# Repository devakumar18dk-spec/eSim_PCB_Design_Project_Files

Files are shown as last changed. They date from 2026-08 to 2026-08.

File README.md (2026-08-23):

<div align="center">

# ⚡ Enhanced Power Supply ESP32

### Wide-Input (7–24 V) ESP32-C3 Development Board — A Complete Embedded Hardware Platform

**Designed & Simulated in FOSSEE eSim (KiCad-based workflow)**


















</div>

<br>

<p align="center">
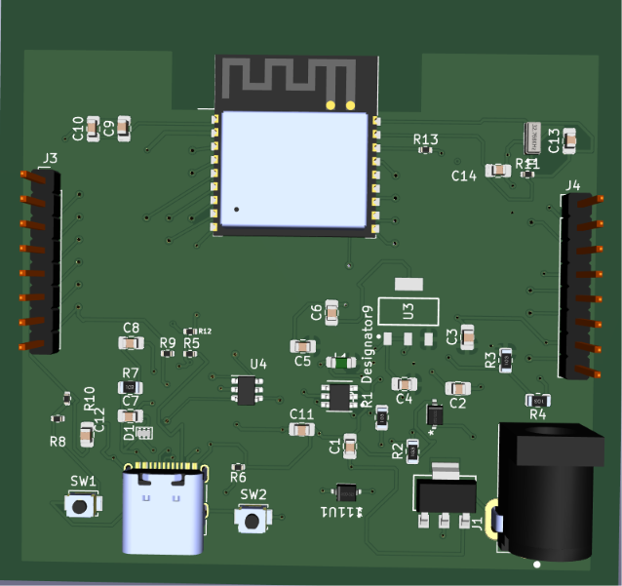
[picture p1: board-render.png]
Enhanced Power Supply ESP32 — 3D Render
  
</p>

<p align="center"><sub>🧊 3D render of the routed 4-layer board — ESP32-C3-WROOM-02, USB-C, DC barrel jack, and dual GPIO headers.</sub></p>

<div align="center">

`Power In (7–24V)` → `Protection` → `5V Buck` → `3.3V LDO` → `ESP32-C3` ⚡

</div>

```bash
git clone https://github.com/devakumar18dk-spec/eSim_PCB_Design_Project_Files.git
```

---

## 📖 Table of Contents

- [Overview](#-overview)
- [Highlights & Features](#-highlights--features)
- [System Architecture](#-system-architecture)
- [Power Architecture](#-power-architecture)
- [USB-C Interface](#-usb-c-interface)
- [Boot & Reset Control](#-boot--reset-control)
- [RTC Timing](#-rtc-timing)
- [GPIO Expansion](#-gpio-expansion)
- [PCB Design (4-Layer)](#-pcb-design-4-layer)
- [📐 Schematic](#-schematic)
- [🖼 PCB Layout](#-pcb-layout)
- [Technical Specifications](#-technical-specifications)
- [Design Verification Checklist](#-design-verification-checklist)
- [Hardware Bring-Up Sequence](#-hardware-bring-up-sequence)
- [Design Workflow](#-design-workflow)
- [Repository Structure](#-repository-structure)
- [Getting Started](#-getting-started)
- [Contributing](#-contributing)
- [License](#-license)
- [Acknowledgements](#-acknowledgements)

---

## 🧭 Overview

This project presents the design and PCB implementation of a custom **ESP32-C3-based development board**, engineered end-to-end using the **FOSSEE eSim electronics design environment**. Rather than functioning as a simple ESP32 breakout, this board is architected as a **complete embedded hardware platform** — integrating wide-range DC power input, robust input protection, two-stage voltage regulation, USB-C connectivity with ESD protection, hardware boot/reset control, RTC timing, and expandable GPIO — all realized on a **four-layer PCB**.

> **Design philosophy:** protect first, convert efficiently, regulate cleanly, then compute. Every subsystem exists to deliver a stable, low-noise supply and a reliable interface to the ESP32-C3.

```
7–24 V DC  →  Protection  →  5 V Buck  →  3.3 V LDO  →  ESP32-C3
```

---

## ✨ Highlights & Features

<table>
<tr>
<td width="50%" valign="top">

### 🔋 Power System
- Wide **7 V – 24 V DC** input range
- Reverse-polarity protection via **P-channel MOSFET**
- **TVS/Zener** transient (surge) protection
- Two-stage regulation: **Buck (5 V) → LDO (3.3 V)**
- Local bulk + high-frequency decoupling at the MCU

### 🔌 Connectivity
- **USB Type-C** interface (16-pin receptacle)
- CC1/CC2 configuration resistors (device/sink mode)
- Dedicated **USBLC6-2SC6** ESD protection on D+/D−
- USB used strictly for data/programming — **not** primary power

</td>
<td width="50%" valign="top">

### 🧠 Control & Expansion
- **ESP32-C3-WROOM-02** central controller
- Dedicated **EN (Reset)** and **IO9 (Boot)** push buttons
- **32.768 kHz RTC crystal** for low-power timekeeping
- **2 × 8-pin, 2.54 mm** GPIO expansion headers

### 🧱 PCB Engineering
- **4-layer stack-up**: Power / Signal / Mixed / Ground
- Dedicated **ESP32 antenna keep-out zone**
- Functionally-grouped component placement
- Continuous ground plane for low-impedance return paths

</td>
</tr>
</table>

---

## 🏗 System Architecture

The board is organized into five functional sections: **Power**, **USB-C**, **Main Controller**, **Boot/Reset**, and **GPIO/Expansion**.

```
                  ESP32-C3 DEVELOPMENT BOARD
                           │
       ┌───────────────────┼───────────────────┐
       │                   │                   │
       ▼                   ▼                   ▼
 POWER SYSTEM         USB-C SYSTEM       CONTROL / I/O
       │                   │                   │
  7–24 V DC           USB Type-C          Boot Button
       │                   │               Reset Button
       ▼                   │                   │
 Input Protection          │                   │
       │                   │                   │
       ▼                   ▼                   ▼
 5 V Buck              ESD Protection      ESP32-C3
       │                   │                   │
       ▼                   ▼              GPIO Headers
 5 V Rail              USB D+/D−
       │
       ▼
 3.3 V LDO
       │
       ▼
  +3.3 V Rail
       │
       ▼
  ESP32-C3 WROOM-02
       │
       └── 32.768 kHz RTC Crystal
```

---

## 🔋 Power Architecture

Every subsystem on this board depends on a stable, protected supply — so power is treated as the primary design driver, not an afterthought.

### Main Power Path

```
DC Input → Protection → Buck Converter (5 V) → LDO (3.3 V) → ESP32-C3
```

The board deliberately avoids converting the full 7–24 V range directly to 3.3 V with a linear regulator. Instead, a **switching regulator** absorbs the large voltage difference efficiently, while an **LDO** performs final, low-noise regulation — the right tool for each job.

<details>
<summary><b>🛡️ Input Protection — click to expand</b></summary>

<br>

| Function | Component | Behavior |
|---|---|---|
| Transient protection | TVS / Zener network | Inactive under normal operation; clamps excess voltage during spikes |
| Reverse-polarity protection | P-channel MOSFET (STN3P6F6) | Low-resistance conduction on correct polarity; blocks reverse voltage |

```
Correct polarity          Incorrect polarity
      │                          │
      ▼                          ▼
P-MOSFET conducts          MOSFET blocks
      │                          │
      ▼                          ▼
Power reaches regulator    Downstream circuitry protected
```

A P-MOSFET is used instead of a conventional diode because it offers **much lower conduction loss**.

</details>

<details>
<summary><b>⚙️ 5 V Buck Conversion — click to expand</b></summary>

<br>

The protected input feeds the **LMR50410-Q1** switching regulator, which converts **7–24 V → 5 V** by transferring energy through controlled switching rather than dissipating the difference as heat.

**Supporting components:** 4.7 µH inductor · bootstrap capacitor · input/output capacitors · feedback resistor network · 10 µF local input capacitor (placed close to the regulator to keep the high-frequency current loop compact).

```
7–24 V ─► Switching Node ─► 4.7 µH Inductor ─► Output Filter ─► 5 V
```

</details>

<details>
<summary><b>🎯 3.3 V LDO Post-Regulation — click to expand</b></summary>

<br>

The 5 V rail feeds an **LM1117-3.3** LDO, which handles only the small **5 V → 3.3 V** step. This division of labor means:

| Stage | Responsibility |
|---|---|
| Buck | Efficient large voltage conversion (7–24 V → 5 V) |
| LDO | Final clean regulation, ripple attenuation, low-impedance supply |

The LDO also provides power-supply rejection within its effective PSRR band, attenuating residual switching ripple before it reaches the ESP32-C3.

</details>

<details>
<summary><b>📎 MCU Decoupling — click to expand</b></summary>

<br>

Local **4.7 µF** (bulk) and **100 nF** (high-frequency) capacitors sit right at the ESP32-C3 supply pins, supplying transient current locally instead of forcing it through long PCB traces from the regulator — reducing supply impedance seen by the controller.

</details>

<div align="right"><sub><a href="#-enhanced-power-supply-esp32">⬆ back to top</a></sub></div>

---

## 🔌 USB-C Interface

The USB-C section is an **independent communication interface**, cleanly separated from the main power path.

| Element | Detail |
|---|---|
| Connector | USB Type-C, 16-pin |
| CC configuration | 2 × 5.1 kΩ on CC1/CC2 → configures board as USB-C sink/device |
| ESD protection | USBLC6-2SC6, placed near the connector |
| Role | Data / programming only — **not** the primary power source |

```
External USB Connector → ESD Protection → ESP32-C3
```

Keeping USB power and main DC power separate lets the board run continuously from the 7–24 V input while still using USB freely for programming and debugging.

---

## 🛠 Boot & Reset Control

| Button | Signal | Function |
|---|---|---|
| Reset | EN | 10 kΩ pull-up; pressing forces EN low and resets the MCU |
| Boot | IO9 | 10 kΩ pull-up; pressing changes boot-strap state to enter programming mode |

```
USB connected → Hold BOOT → Reset ESP32-C3 → Enters programming mode
```

---

## ⏱ RTC Timing

A **32.768 kHz crystal** provides an external low-frequency timing reference for the ESP32-C3 RTC. It's placed close to the module to minimize parasitics and kept away from the buck converter's switching node to avoid noise coupling.

---

## 🧩 GPIO Expansion

Two **8-pin, 2.54 mm pitch headers** expose selected ESP32-C3 GPIOs, turning the board into a reusable development platform for sensors, LEDs, displays, communication modules, and breadboard prototyping.

---

## 🧱 PCB Design (4-Layer)

| Layer | Purpose |
|---|---|
| **F.Cu** (Top) | Power distribution & primary component routing |
| **In1.Cu** | Signal routing (GPIO fan-out from the ESP32-C3) |
| **In2.Cu** | Mixed-purpose routing / secondary distribution |
| **B.Cu** (Bottom) | Continuous ground plane |

<details>
<summary><b>📍 Component Placement Strategy</b></summary>

<br>

| Region | Contents | Rationale |
|---|---|---|
| Upper | ESP32-C3 module, antenna toward board edge | Unobstructed RF environment |
| Central | Buck converter, LDO, protection circuitry, USB-C | Short, low-impedance power connections |
| Lower | Boot/Reset buttons | User accessibility |
| Sides | GPIO headers (left & right) | Convenient external interfacing |

</details>

<details>
<summary><b>📡 Antenna Keep-Out</b></summary>

<br>

A clearly defined **keep-out zone** sits above the ESP32-C3 module — no copper, tracks, or vias are routed through this area, per module manufacturer guidance, to prevent detuning or shielding the integrated antenna.

</details>

<details>
<summary><b>🧵 Routing & Grounding Philosophy</b></summary>

<br>

- **High-current power paths** — short and comparatively wide (DC input, MOSFET, buck, inductor, 5 V rail, LDO)
- **Switching node** — kept as small as practical to limit EMI coupling
- **USB D+/D−** — routed as a matched differential pair, ESD device close to the connector
- **RTC crystal traces** — short, isolated from switching noise
- **Ground plane (B.Cu)** — continuous reference plane minimizing loop area, EMI, and supply noise — especially important given the ESP32-C3's onboard radio

</details>

<details>
<summary><b>🌡️ Thermal Considerations</b></summary>

<br>

Primary heat sources are the **buck converter**, **LDO**, and **protection MOSFET**. The LDO has the most predictable thermal profile since it dissipates the 5 V→3.3 V difference directly — adequate copper area is provided around its thermal pads per datasheet recommendations.

</details>

---

## 📐 Schematic

<p align="center">
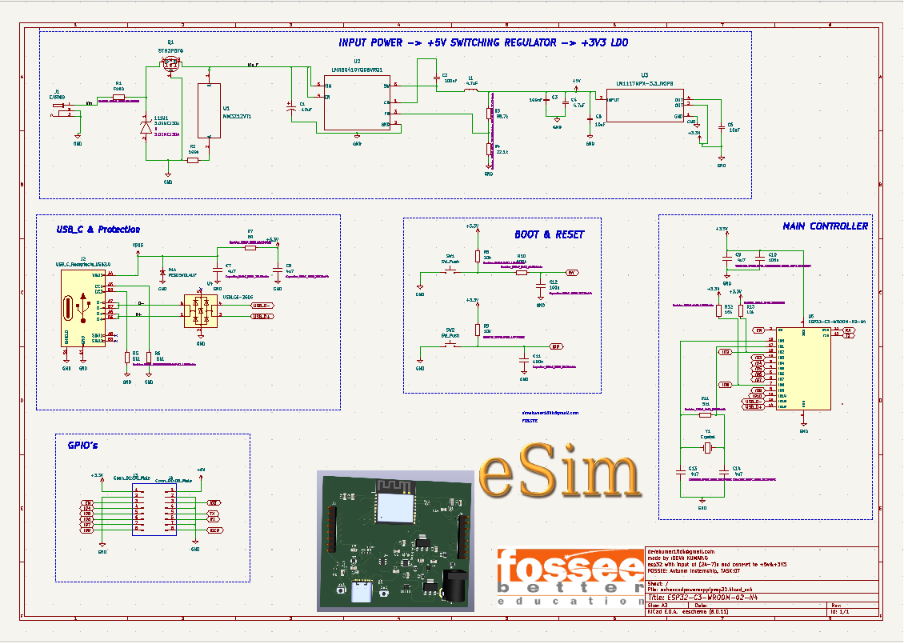
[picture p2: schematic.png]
Full Circuit Schematic
  
</p>

<div align="center">

| 🔋 Input → 5V → 3.3V | 🔌 USB-C & ESD | 🛠 Boot & Reset | 🧠 Main Controller | 🧩 GPIOs |
|:---:|:---:|:---:|:---:|:---:|
| ST6P3F6, LMR50410-Q1, LM1117-3.3 | USB-C receptacle, USBLC6-2SC6 | EN & IO9 push buttons | ESP32-C3-WROOM-02 | 2 × 8-pin headers |

</div>

<p align="center"><sub>📄 Captured entirely in <b>FOSSEE eSim</b> — five functional blocks laid out for clarity: power regulation (top), USB-C/protection, boot/reset, and GPIO breakout (bottom row), with the main ESP32-C3 controller on the right.</sub></p>

---

## 🖼 PCB Layout

The board is routed across **four copper layers**, each with a distinct role. Toggle through the stack below — every view shares the same silhouette so you can trace a single net (e.g. GND) from top to bottom.

<table align="center">
<tr>
<th align="center">🟥 F.Cu — Power / Top Layer</th>
<th align="center">🟩 In1.Cu — Signal Layer</th>
</tr>
<tr>
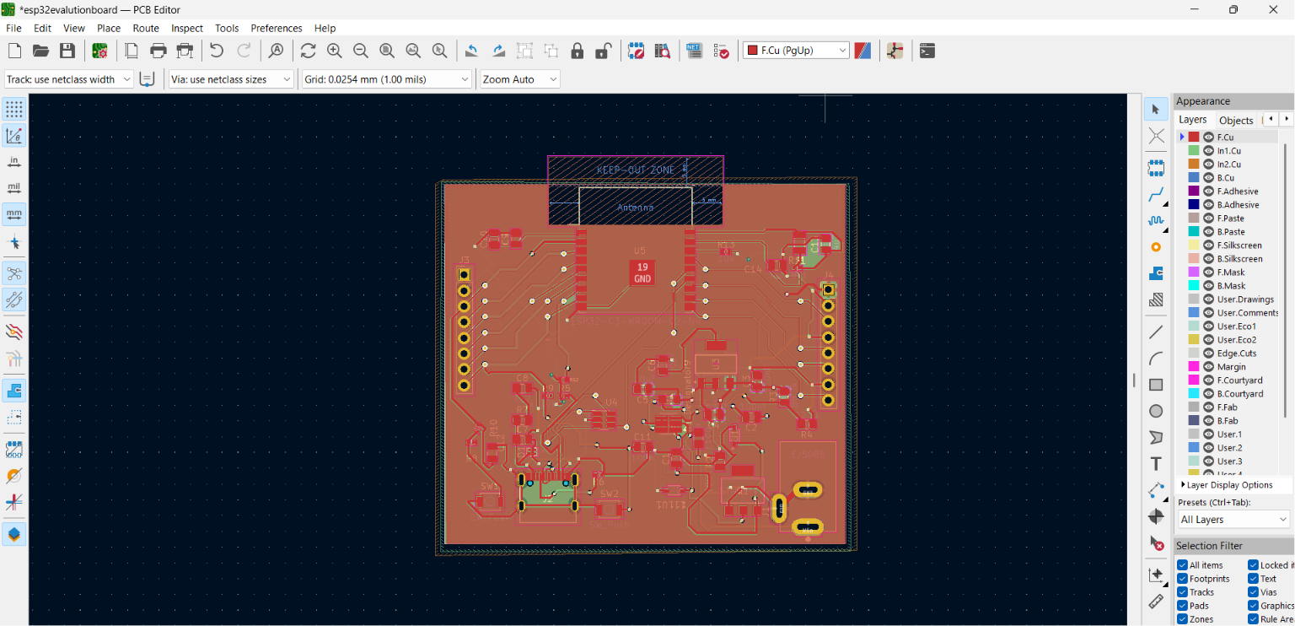
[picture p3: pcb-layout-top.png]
<td></td>
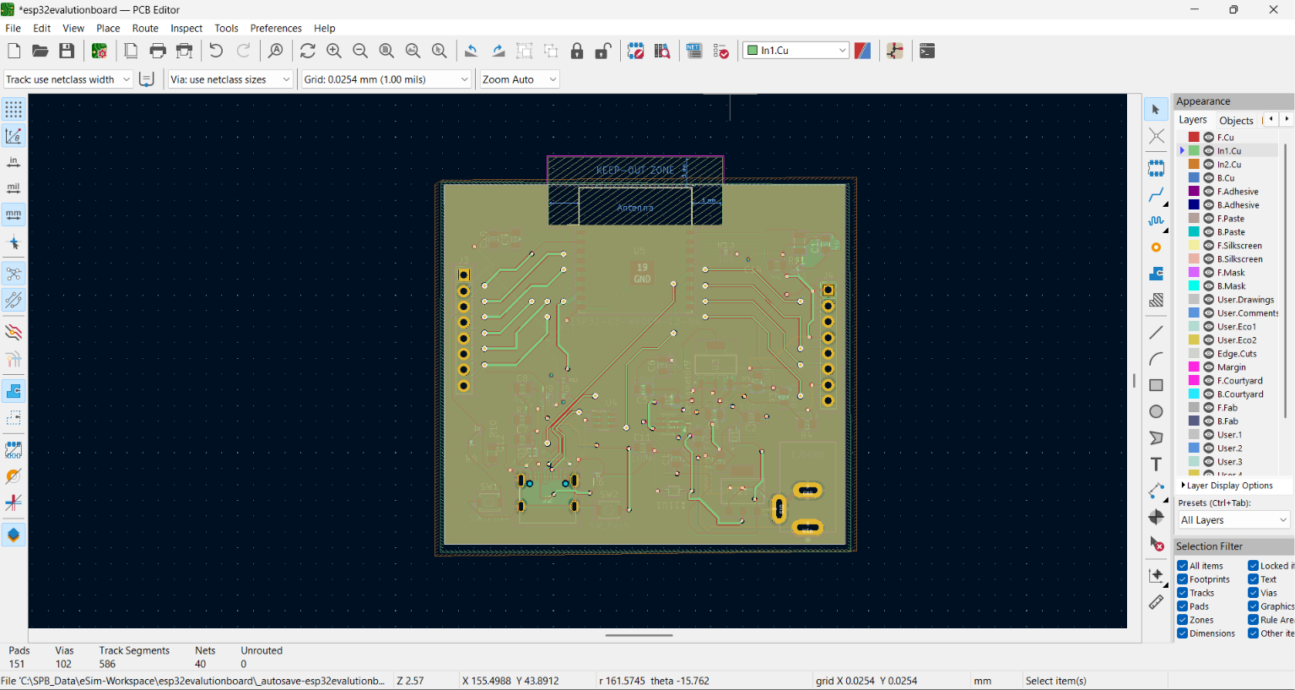
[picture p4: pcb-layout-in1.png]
<td></td>
</tr>
<tr>
<td align="center"><sub>Primary power distribution & component-side routing</sub></td>
<td align="center"><sub>ESP32-C3 GPIO fan-out toward J3 / J4 headers</sub></td>
</tr>
<tr>
<th align="center">🟧 In2.Cu — Mixed Routing Layer</th>
<th align="center">🟦 B.Cu — Ground Plane</th>
</tr>
<tr>
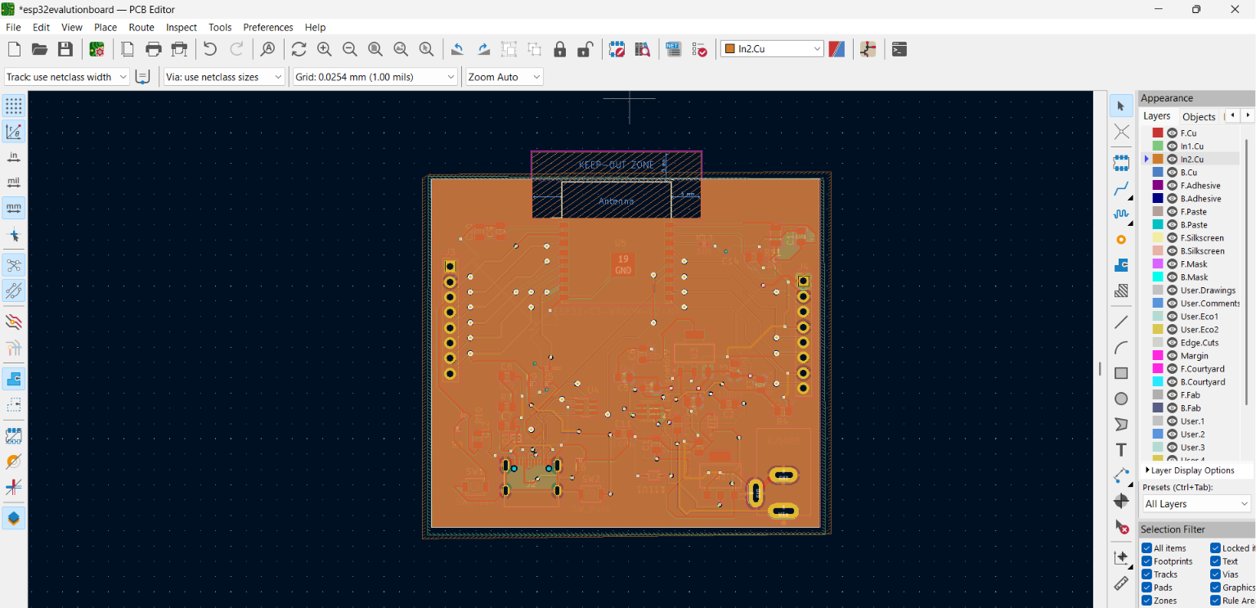
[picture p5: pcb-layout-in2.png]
<td></td>
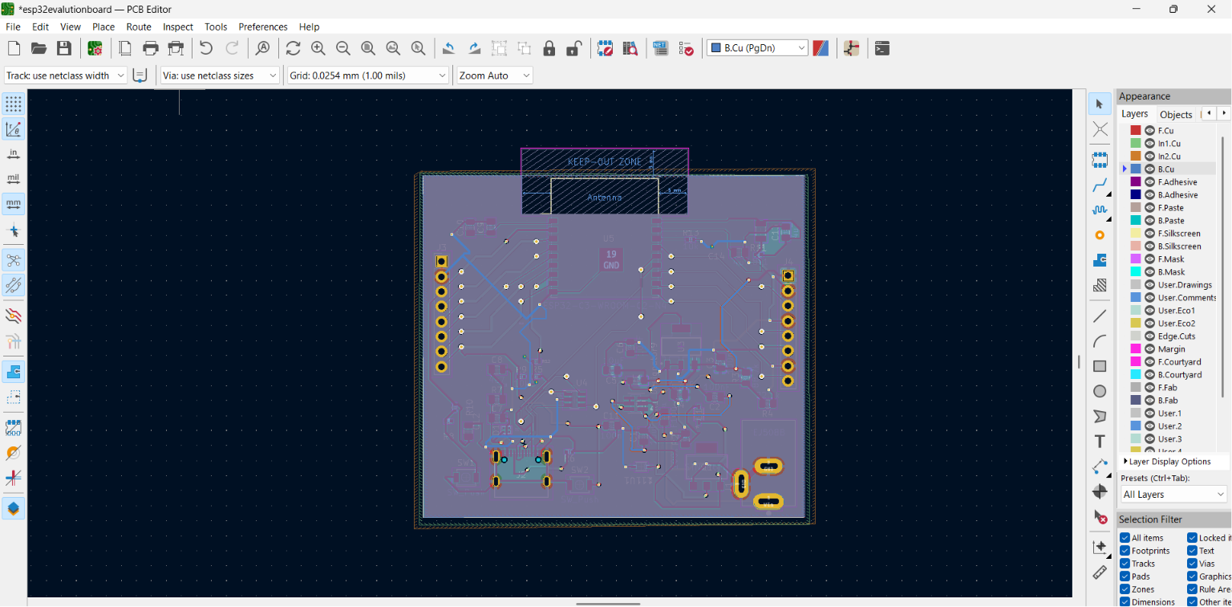
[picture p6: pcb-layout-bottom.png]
<td></td>
</tr>
<tr>
<td align="center"><sub>Secondary power/signal distribution channel</sub></td>
<td align="center"><sub>Continuous ground reference plane</sub></td>
</tr>
</table>

> 🛰️ **Antenna Keep-Out Zone** — visible as the hatched `KEEP-OUT ZONE / Antenna` region above the ESP32-C3 module on every layer. No copper, tracks, or vias are routed through this area to protect RF performance.

<details>
<summary><b>📊 Routing Stats (from PCB editor)</b></summary>

<br>

| Metric | Count |
|---|---|
| Pads | 151 |
| Vias | 102 |
| Nets | 586 |
| Unrouted | 0 ✅ |

</details>

<div align="right"><sub><a href="#-enhanced-power-supply-esp32">⬆ back to top</a></sub></div>

---

## 📋 Technical Specifications

| Specification | Design |
|---|---|
| MCU | ESP32-C3-WROOM-02 |
| Main DC input | 7–24 V |
| Primary power connector | DC input connector |
| Input protection | TVS/Zener + P-channel MOSFET |
| Reverse polarity protection | STN3P6F6 P-MOSFET |
| Buck regulator | LMR50410-Q1 |
| Buck output | 5 V |
| Buck inductor | 4.7 µH |
| Post-regulator | LM1117-3.3 |
| Final logic rail | 3.3 V |
| RTC reference | 32.768 kHz crystal |
| USB connector | USB Type-C, 16-pin |
| USB CC resistors | 5.1 kΩ × 2 |
| USB ESD protection | USBLC6-2SC6 |
| Reset control | EN push button |
| Boot control | IO9 push button |
| Button pull-ups | 10 kΩ |
| GPIO expansion | 2 × 8-pin headers |
| GPIO header pitch | 2.54 mm |
| PCB structure | 4-layer |
| F.Cu | Primary power / component routing |
| In1.Cu | Signal routing |
| In2.Cu | Mixed routing / distribution |
| B.Cu | Ground plane |
| RF provision | ESP32 antenna keep-out |
| Design environment | FOSSEE eSim / KiCad-based workflow |

---

## ✅ Design Verification Checklist

<table>
<tr>
<td width="50%" valign="top">

**Schematic Checks**
- [ ] All power nets verified
- [ ] 3.3 V connections verified
- [ ] 5 V connections verified
- [ ] All ground connections verified
- [ ] ESP32-C3 power pins checked
- [ ] Boot strapping verified
- [ ] EN/reset circuitry verified
- [ ] USB D+/D− connections verified
- [ ] USB CC resistors verified
- [ ] No unintended VBUS-to-3.3 V paths

</td>
<td width="50%" valign="top">

**PCB Checks**
- [ ] Design Rule Check (DRC) passed
- [ ] Track widths verified
- [ ] Clearances verified
- [ ] Via placement checked
- [ ] Copper-zone connections checked
- [ ] Antenna keep-out respected
- [ ] Silkscreen overlaps checked
- [ ] Connector orientation verified
- [ ] Footprint pin numbering verified
- [ ] Mounting/mechanical dimensions verified

</td>
</tr>
</table>

<div align="right"><sub><a href="#-enhanced-power-supply-esp32">⬆ back to top</a></sub></div>

---

## 🧪 Hardware Bring-Up Sequence

> Do **not** connect the ESP32 module immediately after fabrication — follow a controlled sequence.

| Step | Test | Expected Result |
|---|---|---|
| 1 | Input protection | Protected input rail stable across 7–24 V |
| 2 | Buck converter | ~**+5 V** at buck output (before connecting downstream circuitry) |
| 3 | LDO | ~**+3.3 V** at LDO output |
| 4 | MCU power | ESP32-C3 receives correct 3.3 V supply |
| 5 | Reset | Pressing EN resets the MCU |
| 6 | Boot | IO9 + reset sequencing enters programming mode |
| 7 | USB | USB enumeration / programming succeeds |
| 8 | GPIO | Expansion headers verified with simple GPIO firmware |
| 9 | RTC | 32.768 kHz RTC functionality confirmed |

---

## 🔁 Design Workflow

```
System Requirements → Circuit Architecture → Component Selection
        → Schematic Capture (eSim) → Electrical Connectivity Verification
        → Footprint Assignment → PCB Layout → 4-Layer Stack-up
        → Component Placement → Power Routing → Signal Routing
        → Ground Plane → Antenna Keep-Out → Design Rule Check
        → Gerber / Manufacturing Files → PCB Fabrication → Hardware Testing
```

---

## 🗂 Repository Structure

```
eSim_PCB_Design_Project_Files/
├── assets/
│   └── images/
│       ├── board-render.png       # 3D render
│       ├── schematic.png          # Full eSim schematic
│       ├── pcb-layout-top.png     # F.Cu — power layer
│       ├── pcb-layout-in1.png     # In1.Cu — signal layer
│       ├── pcb-layout-in2.png     # In2.Cu — mixed layer
│       └── pcb-layout-bottom.png  # B.Cu — ground plane
├── hardware/
│   ├── schematic/          # eSim / KiCad schematic project files
│   ├── pcb/                # PCB layout project files
│   └── gerbers/            # Manufacturing output (Gerbers, drill files, BOM)
├── docs/
│   └── technical-report.md # Full design & verification report
├── firmware/                # (optional) example/bring-up firmware
├── LICENSE
└── README.md
```

---

## 🚀 Getting Started

1. **Clone the repository**
   ```bash
   git clone https://github.com/devakumar18dk-spec/eSim_PCB_Design_Project_Files.git
   cd eSim_PCB_Design_Project_Files
   ```
2. **Open the schematic/PCB** in FOSSEE eSim or KiCad from the `hardware/` directory.
3. **Review the Gerbers** in `hardware/gerbers/` before sending to fabrication.
4. **Follow the [Hardware Bring-Up Sequence](#-hardware-bring-up-sequence)** after assembly.
5. **Flash firmware** over USB-C once power rails are verified.

---

## 🤝 Contributing

Contributions, issues, and design suggestions are welcome! Feel free to open a pull request or start a discussion if you'd like to improve the power architecture, layout, or documentation.

---

## 📄 License

This project is released under the **MIT License** — see [`LICENSE`](LICENSE) for details. *(Update if a different license applies.)*

---

## 🙌 Acknowledgements

- **FOSSEE eSim** — schematic capture and simulation environment
- **KiCad** — PCB layout workflow
- **Espressif Systems** — ESP32-C3-WROOM-02 module

---

<div align="center">

### 🧩 Built as a complete embedded hardware platform — not just an ESP32 carrier board.

**Wide-range power management · Protection · Wireless processing · USB-C · Hardware boot control · RTC · Expandable I/O**
**— all in a single four-layer PCB.**




**⭐ If this project helped you, consider starring the repository!**

[⬆ Back to top](#-enhanced-power-supply-esp32)

</div>

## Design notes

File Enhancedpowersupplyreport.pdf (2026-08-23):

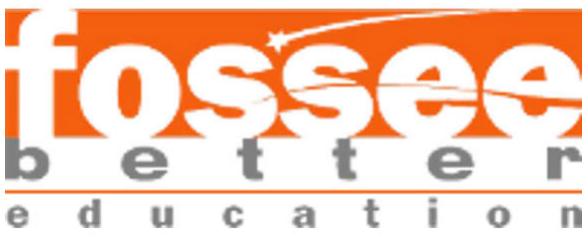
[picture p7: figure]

# eSim

SEMESTER LONG INTERNSHIP – AUTUMN 2026 INTERNSHIP SCREENING TASK REPORT Task 7 – PCB Design using eSim

# Enhanced Power Supply ESP32

Wide-Input (7–24 V) ESP32-C3 Development Board

Prepared by Deva Kumar G, II Year Department of VLSI Design and Technology Chennai Institute of Technology

PCB – ESP32C3-EPS

Enhanced Power Supply ESP32 — FOSSEE Autumn Internship 2026 | Page 2

# 1. Project Overview

This report presents the complete printed circuit board (PCB) design and schematic files for a custom, wide-input ESP32-C3 microcontroller development board. The design was developed as part of the screening task for the FOSSEE Autumn Internship 2026 program conducted by IIT Bombay.

The primary objective of this project was to design a fully functional, manufacturable development board centred around the ESP32-C3-WROOM-02 module — one that goes beyond a simple breakout board. Rather than exposing the module directly to an external supply, the board implements a complete power architecture that accepts a wide 7–24 V DC input, protects against reverse polarity and transient events, and steps the supply down through a two-stage regulator chain before it ever reaches the microcontroller.

The design was realised as a custom 4-layer PCB stack-up, optimised for power distribution, signal integrity, and RF-aware component placement around the module's integrated antenna.

## Key Project Details

Microcontroller | ESP32-C3-WROOM-02 (RISC-V single-core, 160 MHz, Wi-Fi + BLE 5, integrated antenna)
Design Tools | FOSSEE eSim 2.5 (schematic capture) KiCad (PCB layout, integrated via eSim)
Power Input | Wide-range 7–24 V DC via dedicated DC input connector
Regulation Architecture | Protected input → LMR50410-Q1 buck (5 V) → LM1117-3.3 LDO (3.3 V)
USB Interface | USB Type-C, 16-pin — data/programming only, not the primary power source
PCB Stack-up | 4-layer: F.Cu (power) / In1.Cu (signal) / In2.Cu (mixed) / B.Cu (ground)
Verification Status | Schematic connectivity and PCB design-rule checks completed with zero unresolved errors

The finished design includes a fully routed 4-layer stack-up and a 3D visual model for verifying component placement and mechanical fit ahead of fabrication.

# 2. Circuit Description

## 2.1 Power Supply Section

The board operates from a two-stage regulated supply rather than a single linear conversion from the wide input range. The external 7–24 V DC source first passes through an input protection stage comprising a TVS/Zener transient-clamping network and a P-channel MOSFET (STN3P6F6) configured for reverse-polarity protection. Under correct polarity the MOSFET conducts with very low resistance; if the supply is connected in reverse, it blocks the path entirely and protects every downstream component.

The protected input then feeds the LMR50410-Q1 synchronous buck converter, which efficiently steps the 7–24 V input down to an intermediate 5 V rail using a 4.7 uH inductor and a 10 uF local input capacitor placed close to the regulator to keep the high-frequency switching loop compact. The 5 V rail is not used directly by the MCU — it feeds an LM1117-3.3 LDO, which performs the final, low-noise regulation down to 3.3 V. Splitting the conversion this way lets the buck stage absorb the large voltage difference efficiently,

Enhanced Power Supply ESP32 — FOSSEE Autumn Internship 2026 | Page 3

while the LDO concentrates purely on ripple rejection and supply cleanliness for the sensitive digital domain.

Local 4.7 uF bulk and 100 nF high-frequency decoupling capacitors are placed directly at the ESP32-C3 power pins to supply transient current locally and minimise supply impedance during rapid load changes (e.g. Wi-Fi transmit bursts).

## 2.2 Clock and Timing

A 32.768 kHz crystal is connected to the ESP32-C3's RTC circuitry to provide an accurate low-power timing reference for real-time clock and deep-sleep wake functions. The crystal is placed close to the module to minimise parasitic trace length and is routed away from the buck converter's switching node to avoid noise coupling into the oscillator.

## 2.3 Connectivity and Interfaces

- USB Type-C Port: A 16-pin USB-C receptacle provides the programming/debugging interface. Two 5.1 kΩ resistors on CC1/CC2 configure the board as a USB-C sink/device, and the D+/D− lines are protected by a dedicated USBLC6-2SC6 ESD device placed close to the connector.
- GPIO Expansion: Two 8-pin, 2.54 mm pitch headers (J3/J4) break out selected ESP32-C3 GPIOs for external sensors, actuators, displays, and breadboard prototyping.
- Power Input: A dedicated DC barrel/PCB-mount connector accepts the primary 7–24 V supply, kept electrically independent from the USB-C data interface.

## 2.4 User Interface

Two user-accessible push-button switches are provided: EN (Reset), pulled up through 10 kΩ and pulled low on press to reset the module, and IO9 (Boot), which changes the GPIO9 strap state during power-up/reset to enter the UART bootloader for firmware programming.

## 2.5 Peripheral Summary

Interface | Specification
Wireless | Wi-Fi 4 (802.11 b/g/n) + Bluetooth LE 5, integrated PCB antenna
USB | 1 × USB Type-C (Full-Speed, programming/debug)
GPIO | 2 × 8-pin, 2.54 mm expansion headers
Timing | 32.768 kHz external RTC crystal
Control | EN (reset) and IO9 (boot) push buttons
Power Rails | 5 V intermediate rail, 3.3 V logic rail

# 3. Schematic Screenshots

The complete schematic was captured in FOSSEE eSim and organised into clearly labelled functional blocks for readability and maintainability.

## 3.1 Full Schematic Overview

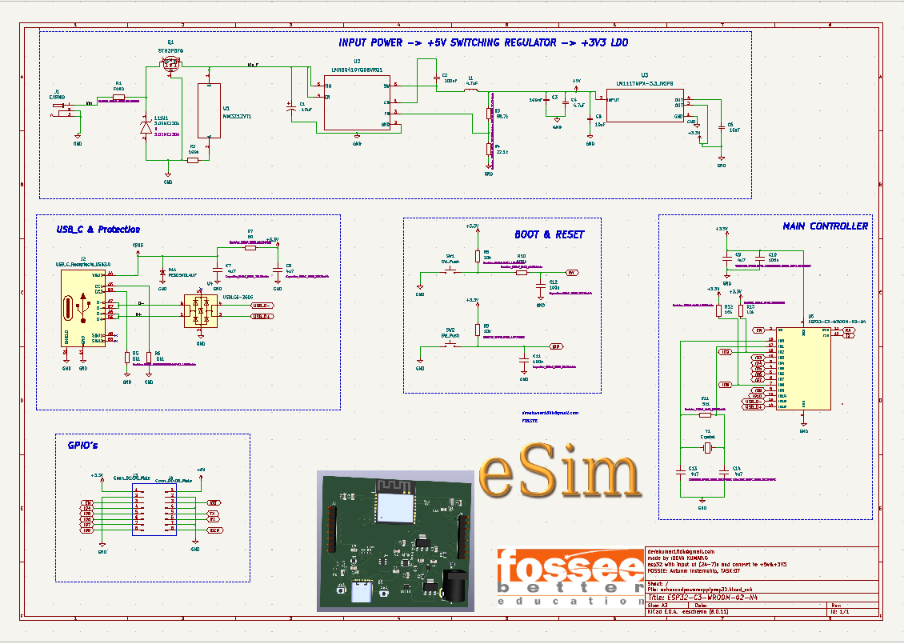
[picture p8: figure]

Enhanced Power Supply ESP32 — FOSSEE Autumn Internship 2026 | Page 4

The schematic sheet below provides a top-level view of the entire circuit: the power-regulation chain (input protection → 5 V buck → 3.3 V LDO) across the top, USB-C & protection, boot/reset, and GPIO break-out blocks along the bottom, and the ESP32-C3 main controller block on the right — all interconnected through labelled nets.

Figure 3.1 – Full schematic, captured in FOSSEE eSim

Note: Wire labels were used for power nets throughout the schematic (e.g. +3V3, +5V, GND) instead of floating global power symbols. This keeps the sheet visually clean while preserving correct electrical connectivity between blocks.

# 4. Footprint Assignment Details

Component footprints were assigned in the PCB workflow using standard eSim/KiCad libraries, cross-checked against each part's datasheet package outline to ensure correct pad geometry, courtyard clearance, and polarity marking before routing began.

## 4.1 Power Components

- P-MOSFET (STN3P6F6): SOT-23 package, reverse-polarity protection stage.
- Buck Regulator (LMR50410-Q1): SOT-23-6 package, with 4.7 uH shielded inductor footprint and associated input/output/bootstrap capacitor pads.
- LDO (LM1117-3.3): SOT-223 package, oriented for adequate copper pour around the thermal pad.

## 4.2 Passive Components

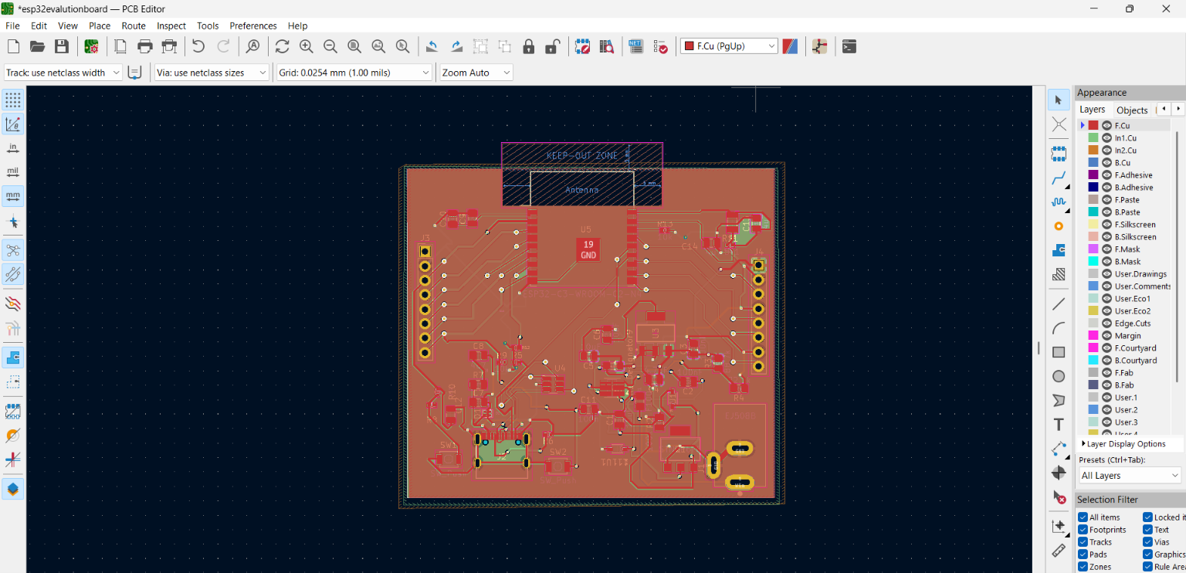
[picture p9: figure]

Enhanced Power Supply ESP32 — FOSSEE Autumn Internship 2026 | Page 5
- Resistors & Capacitors: 0603 (1608 metric) SMD footprints — used for CC configuration resistors, pull-ups, and decoupling/bulk capacitors.
- RTC Crystal: 2-pad SMD crystal footprint with datasheet-specified load capacitors.

## 4.3 Connectors

- USB Type-C: 16-pin SMD receptacle footprint with mechanical anchor/ground tabs for board-edge structural support.
- DC Power Input: Through-hole barrel/PCB-mount connector footprint rated for the 7–24 V range.
- GPIO Headers (J3/J4): Standard 2.54 mm pitch, single-row, 8-way male header footprints.

## 4.4 User Interface

- Tactile Switches (EN, IO9): Standard 6×6 mm SMD tactile switch footprint.

# 5. PCB Layout

The PCB layout was completed using KiCad's PCB editor, accessed through the eSim integration. The board is implemented as a 4-layer stack-up, with functional grouping used to keep the ESP32-C3 module's RF section, the power-conversion cluster, and the user-accessible controls in clearly separated regions of the board.

## 5.1 Front Copper Layer (F.Cu) — Power / Component Routing

The front copper layer carries the primary power distribution and component-side connections: the protected input rail, the 5 V buck output, and the 3.3 V distribution to the ESP32-C3 and its decoupling network. Power components are grouped tightly in the central/lower region to keep high-current paths short.

Figure 5.1 – F.Cu (top/power layer), showing the antenna keep-out zone above the module

## 5.2 Inner Layer 1 (In1.Cu) — Signal Routing

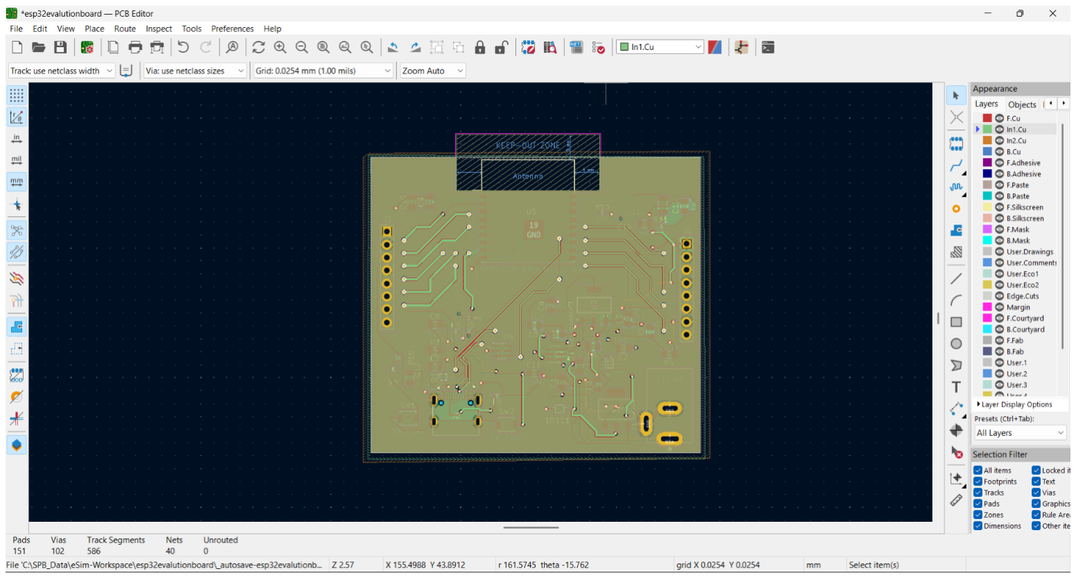
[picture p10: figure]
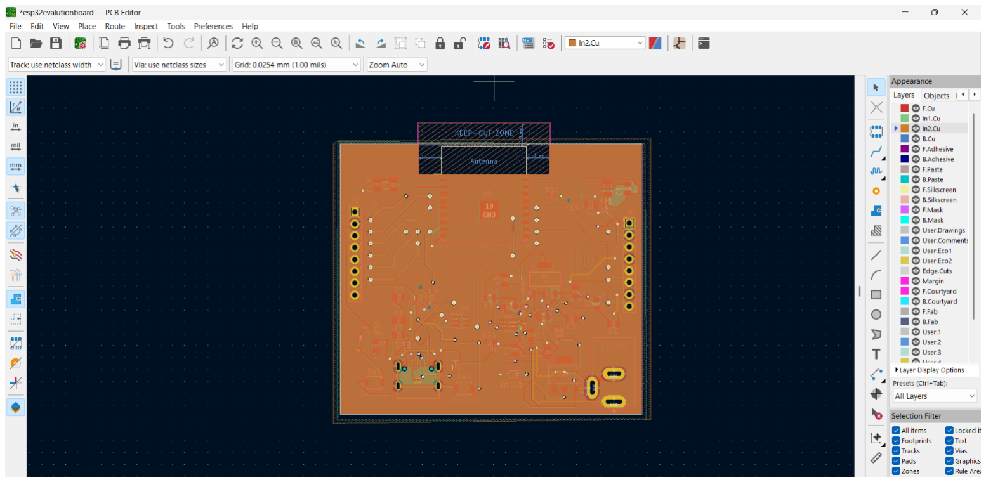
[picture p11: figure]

Enhanced Power Supply ESP32 — FOSSEE Autumn Internship 2026 | Page 6

The first internal copper layer is dedicated to signal routing. The ESP32-C3 sits centrally with GPIO connections fanning outward toward the J3/J4 headers, reducing congestion on the outer copper layer.

Figure 5.2 – In1.Cu, GPIO fan-out from the ESP32-C3 to the expansion headers

## 5.3 Inner Layer 2 (In2.Cu) — Mixed Routing / Distribution

The second internal layer provides additional routing channels for both signal and power nets where the outer layers become congested, preventing excessive routing density on the front and back copper.

Figure 5.3 – In2.Cu, secondary power/signal distribution channel

## 5.4 Back Copper Layer (B.Cu) — Ground Plane

The back copper layer is dedicated almost entirely to a continuous ground plane, giving every signal a low-impedance return path directly beneath it. This is especially important for the ESP32-C3's integrated radio, which is sensitive to its surrounding electromagnetic environment.

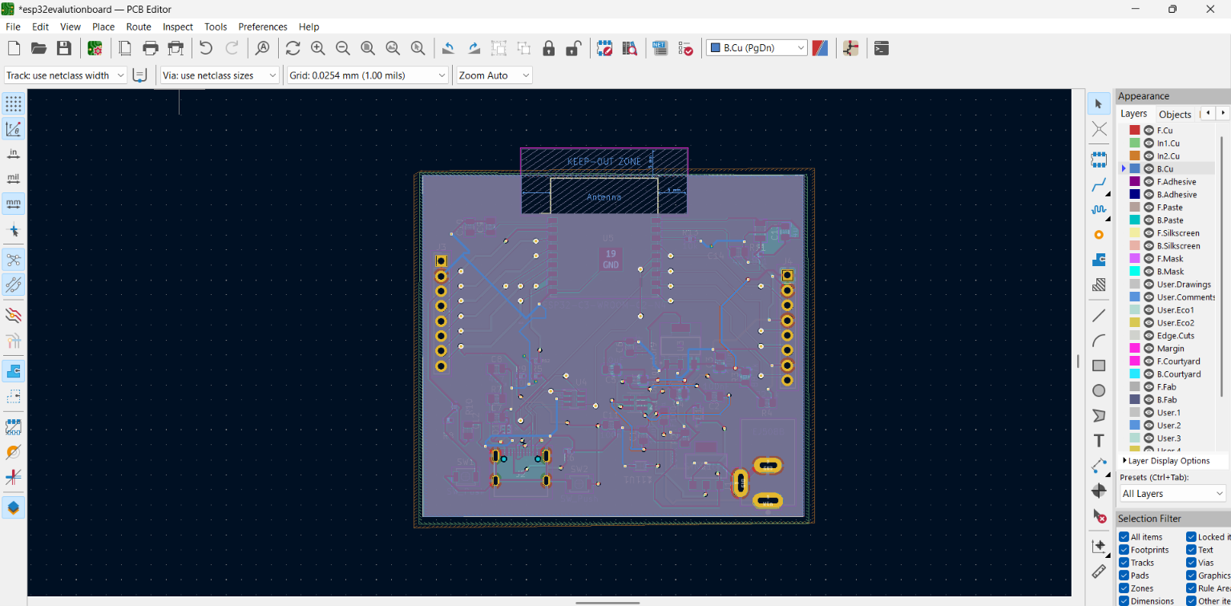
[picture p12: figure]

Enhanced Power Supply ESP32 — FOSSEE Autumn Internship 2026 | Page 7

Figure 5.4 – B.Cu, continuous ground reference plane

Antenna Keep-Out Zone: A clearly marked keep-out region is enforced above the ESP32-C3 module on every copper layer (visible as the hatched “KEEP-OUT ZONE / Antenna” area). No copper, tracks, or vias are routed through this region, in line with the module manufacturer's RF layout guidance, to prevent detuning or shielding the integrated antenna.

# 6. Routing Methodology

## 6.1 Layer Stack-up Strategy

The 4-layer stack-up was chosen specifically for a mixed power/RF/digital design of this kind:

Layer | Name | Function | Purpose
1 | F.Cu (Front) | Power + component routing | Primary power distribution, short high-current paths
2 | In1.Cu (Inner 1) | Signal routing | GPIO fan-out from ESP32-C3 to expansion headers
3 | In2.Cu (Inner 2) | Mixed routing / distribution | Secondary power & signal routing channel
4 | B.Cu (Back) | Ground plane | Continuous low-impedance return path

This arrangement ensures the ground plane on B.Cu sits close to the routing layers above it, minimising loop area and unwanted electromagnetic coupling — particularly important given the ESP32-C3's onboard radio.

## 6.2 Signal & Power Routing Guidelines

- High-current power paths (DC input, MOSFET, buck converter, inductor, 5 V rail, LDO) are kept short and comparatively wide.
- Switching node of the buck converter is kept as small and compact as practical to limit EMI coupling into adjacent traces.

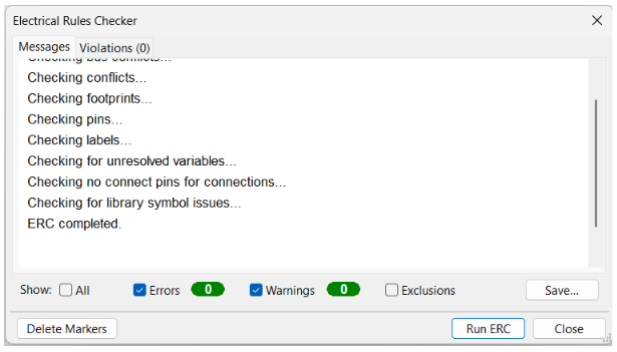
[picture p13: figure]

Enhanced Power Supply ESP32 — FOSSEE Autumn Internship 2026 | Page 8
- Decoupling capacitors are placed as close as physically possible to the ESP32-C3 power pins.
- USB D+/D− are routed as a matched differential pair, with the ESD protection device placed close to the connector to keep the unprotected trace length short.
- RTC crystal traces are kept short and isolated from the switching regulator's noisy node.
- Ground plane continuity: no signal traces cross splits or gaps in the ground plane, avoiding return-path discontinuities.

## 6.3 Design Rule Constraints

All routing was carried out within standard 4-layer PCB fabrication constraints:

- Minimum trace width and spacing within standard manufacturer capabilities.
- Minimum via drill size and annular ring within standard fabrication tolerances.
- Copper-to-edge clearance maintained around the board outline.
- No acid traps or acute-angle traces in the routing.

# 7. Design Verification

Before committing the design to fabrication, both schematic-level and PCB-level checks were carried out in eSim/KiCad.

## 7.1 Schematic Checks (ERC)

- Every power net verified (protected input, 5 V, 3.3 V, GND).
- ESP32-C3 power pins and decoupling network checked.
- EN/reset and IO9/boot strapping circuitry verified.
- USB D+/D− connections and CC resistor values verified.
- Checked for unintended VBUS-to-3.3 V connections.

Figure 7.1 – Electrical Rules Checker: 0 errors, 0 warnings on ERC completion

## 7.2 PCB Checks (DRC)

- Design Rule Check run with zero unresolved clearance/track-width violations.
- Via placement, pad sizing, and copper-zone connections verified.

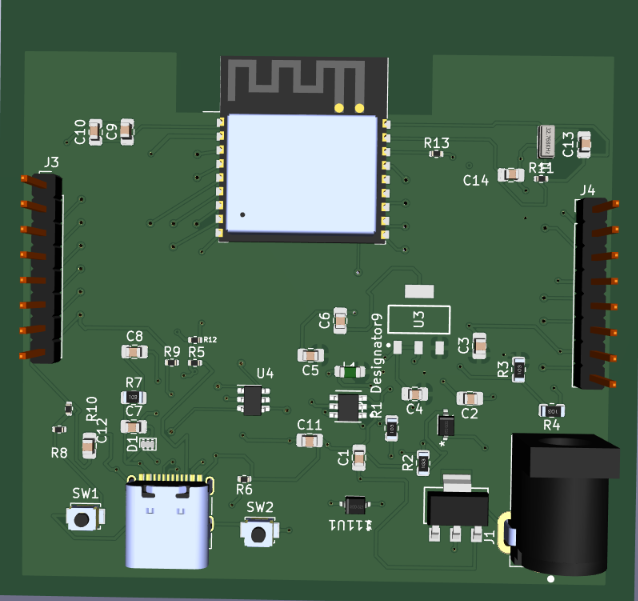
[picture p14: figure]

Enhanced Power Supply ESP32 — FOSSEE Autumn Internship 2026 | Page 9
- Antenna keep-out region checked against the module manufacturer's guidance.
- Silkscreen overlaps, connector orientation, and footprint pin numbering verified.
- Board outline and mounting/mechanical dimensions verified.
Result: the schematic and PCB layout passed the above checks with all nets fully routed and no outstanding design-rule violations, indicating the board is ready for Gerber export and fabrication.

# 8. 3D Model

A 3D render of the board was generated from the routed PCB layout to visually verify component placement, connector accessibility, and overall mechanical form factor ahead of fabrication.

## 8.1 Isometric View

The render below shows the ESP32-C3-WROOM-02 module at the top of the board with a clear area around its antenna, the power-conversion cluster and USB-C/DC input in the centre, boot/reset buttons along the bottom edge, and the two GPIO expansion headers along the left and right sides.

Figure 8.1 – 3D render of the fully routed board

# 9. Design Considerations and Conclusion

## 9.1 Design Considerations

Power Integrity: The two-stage buck + LDO architecture means the LDO never has to absorb the full 7–24 V range — it handles only the 5 V→3.3 V step, giving a clean, low-impedance supply to the ESP32-C3 even under wide input variation.

Enhanced Power Supply ESP32 — FOSSEE Autumn Internship 2026 | Page 10

Signal Integrity: The 4-layer stack-up gives every routed signal an adjacent reference plane, minimising return-current loop area and reducing coupling into the RTC crystal and USB differential pair.

RF Considerations: A dedicated antenna keep-out zone above the ESP32-C3 module, free of copper, tracks, and vias, protects the integrated antenna's radiation performance.

Protection: Reverse-polarity protection (P-MOSFET) and transient protection (TVS/Zener) on the input, plus dedicated USB ESD protection, guard the board against the most common field-failure modes.

Manufacturability: The design was routed within standard 4-layer fabrication constraints — standard trace/space, via drill sizes, and copper-to-edge clearances — avoiding the need for premium manufacturing processes.

Expandability: Two 2.54 mm GPIO headers turn the board from a closed embedded controller into a reusable development platform for sensors, displays, and other peripherals.

## 9.2 Conclusion

This project delivers a complete, manufacturable PCB design for a wide-input ESP32-C3 development board. The design achieves the following key outcomes:

- Verified design — schematic connectivity and PCB design-rule checks completed with no outstanding errors.
- Robust wide-input power architecture — a 7–24 V input is protected, converted, and regulated through a two-stage buck + LDO chain before reaching the MCU.
- Professional-grade 4-layer stack-up — dedicated signal, distribution, and ground layers support both power integrity and RF performance.
- Practical connectivity — USB-C programming/debug, RTC timing, hardware boot/reset control, and GPIO expansion make the board a genuinely reusable development platform.
- Complete documentation — schematic, layer-by-layer PCB views, routing methodology, verification checks, and a 3D render are all included for full design transparency.
Overall, the project demonstrates the complete hardware-development workflow — from system architecture and component selection, through schematic design and protection circuitry, to multilayer PCB layout, RF-aware placement, and design verification — using the FOSSEE eSim / KiCad-based design environment. The resulting board is not merely an ESP32 carrier board; it is a complete embedded hardware platform combining wide-range power management, protection, wireless processing, USB connectivity, hardware boot control, RTC support, and expandable I/O in a single four-layer PCB design.
Designed by Deva Kumar G | FOSSEE Autumn Internship 2026 — IIT Bombay

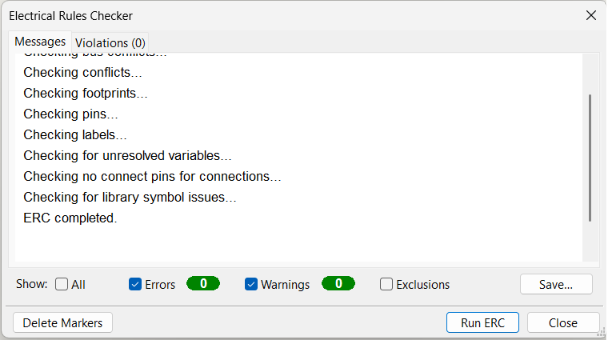
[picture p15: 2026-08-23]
Schematic_erc.png

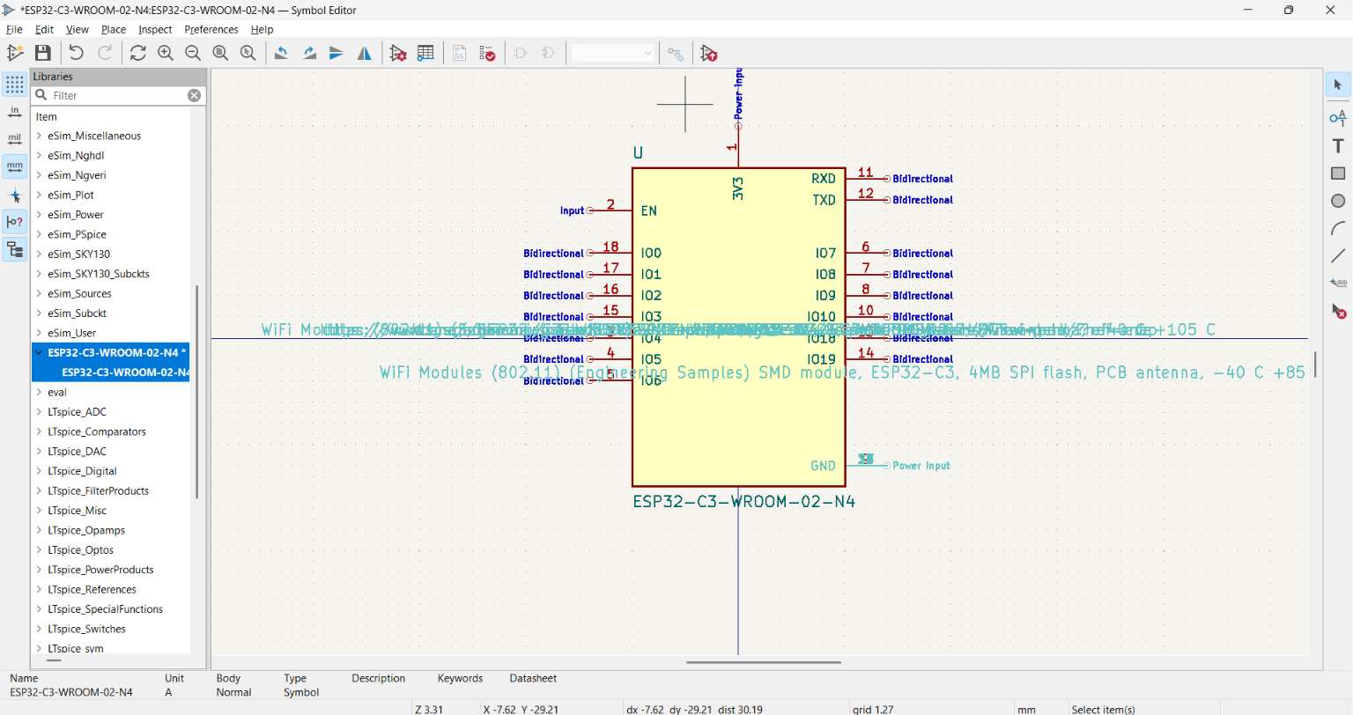
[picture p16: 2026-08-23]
enhancedpowersupplyesp32/images/esp32-c3-wroom-02-N4_symbolediting.png

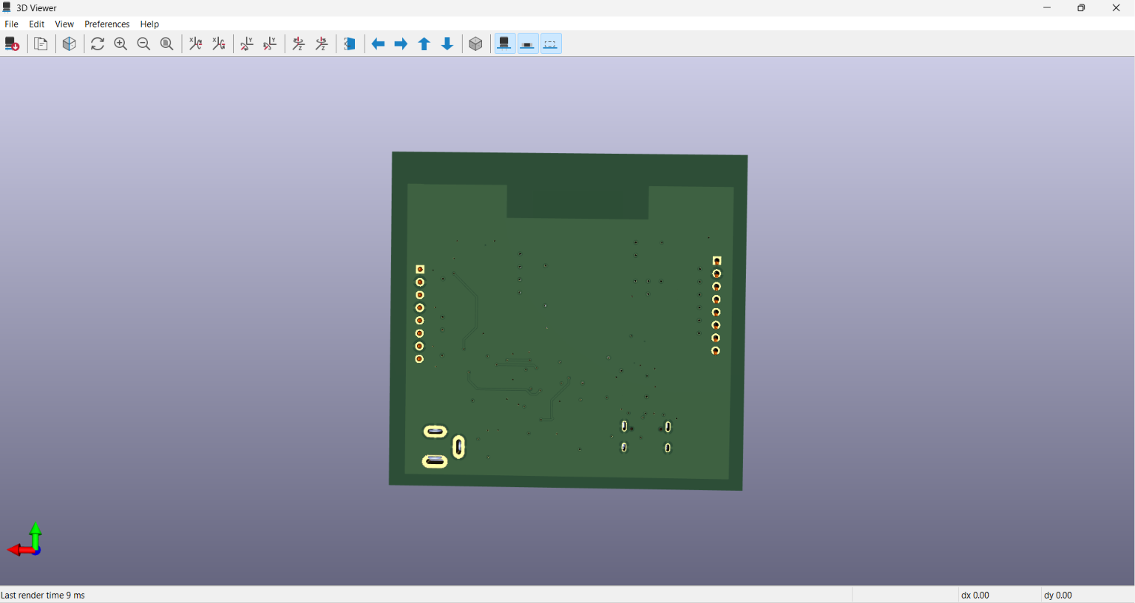
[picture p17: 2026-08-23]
enhancedpowersupplyesp32/images/3d_image_03.png

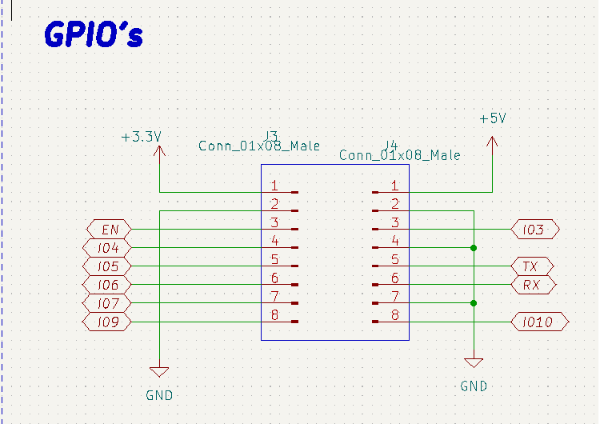
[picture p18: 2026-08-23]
enhancedpowersupplyesp32/images/GPIO's.png

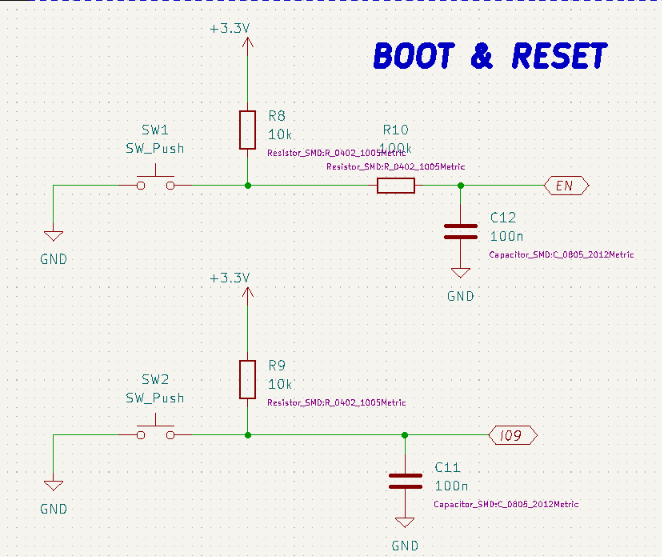
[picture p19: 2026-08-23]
enhancedpowersupplyesp32/images/BOOT&RESET.png

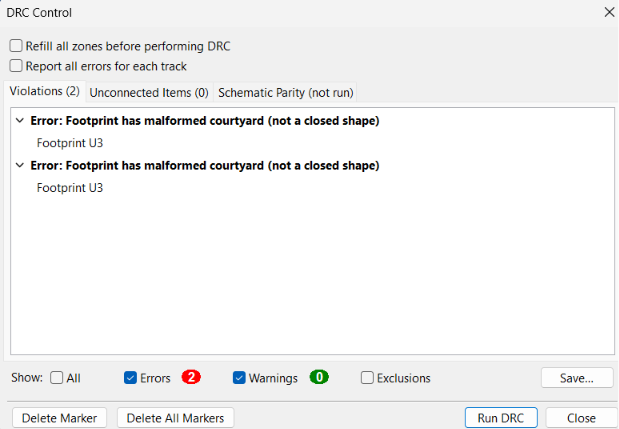
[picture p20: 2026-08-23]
PCB_layout_erc_explanation.png

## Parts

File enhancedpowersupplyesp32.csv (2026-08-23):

Source: | C:\SPB_Data\eSim-Workspace\esp32evalutionboard\esp32evalutionboard.kicad_sch
Date: | 22-08-2026 04:37:48
Tool: | Eeschema (6.0.11)
Generator: | C:\FOSSEE\KiCad\bin\scripting\plugins/bom_csv_grouped_by_value_with_fp.py
Component Count: | 43
Ref | Qnty | Value | Cmp name | Footprint | Description | Vendor
111U1, | 1 | 3.0SMCJ30A | 3.0SMCJ30A | footprints:SOD-323_1P8X1P35_ONS | ESD Suppressors / TVS Diodes TVS 3KW 30V 5%UNI DO-214AB TR13 RoHS
C1, C5, C6, | 3 | 10uF | cap | Capacitor_SMD:C_0805_2012Metric
C2, C3, | 2 | 100nF | cap | Capacitor_SMD:C_0805_2012Metric
C4, | 1 | 4.7uF | cap | Capacitor_SMD:C_0805_2012Metric
C7, C9, C13, C14, | 4 | 4u7 | capacitor | Capacitor_SMD:C_0805_2012Metric
C8, | 1 | 4u7 | capacitor | Capacitor_SMD:C_0805_2012Metric
C10, C11, C12, | 3 | 100n | capacitor | Capacitor_SMD:C_0805_2012Metric
D1, | 1 | PESD5V0L4UF | PESD5V0L4UF | Package_TO_SOT_SMD:SOT-886 | Low capacitance unidirectional quadruple ESD protection diode array, 5.0V, Common Anode, SOT-886
J1, | 1 | EJ508B | EJ508B | EJ508B:MPD_EJ508B
J2, | 1 | USB_C_Receptacle_USB2.0 | USB_C_Receptacle_USB2.0 | Connector_USB:USB_C_Receptacle_G-Switch_GT-USB-7010ASV | USB 2.0-only Type-C Receptacle connector
J3, J4, | 2 | Conn_01x08_Male | Conn_01x08_Male | Connector_PinHeader_2.54mm:PinHeader_1x08_P2.54mm_Vertical | Generic connector, single row, 01x08, script generated (kicad-library-utils/schlib/autogen/connector/)
L1, | 1 | 4.7uF | ind | Inductor_SMD:L_0805_2012Metric_Pad1.05x1.20mm_HandSolder
Q1, | 1 | STN3P6F6 | STN3P6F6 | STN3PF6:SOT223_STN3_STM
R1, | 1 | F100 | resistor | Resistor_SMD:R_0805_2012Metric
R2, | 1 | 100k | resistor | Resistor_SMD:R_0805_2012Metric
R3, | 1 | 88.7k | resistor | Resistor_SMD:R_0805_2012Metric
R4, | 1 | 22.1k | resistor | Resistor_SMD:R_0805_2012Metric
R5, | 1 | 5k1 | resistor | Resistor_SMD:R_0402_1005Metric
R6, R11, | 2 | 5k1 | resistor | Resistor_SMD:R_0402_1005Metric
R7, | 1 | 0R | resistor | Resistor_SMD:R_0805_2012Metric
R8, R9, R12, R13, | 4 | 10k | resistor | Resistor_SMD:R_0402_1005Metric
R10, | 1 | 100k | resistor | Resistor_SMD:R_0402_1005Metric
SW1, SW2, | 2 | SW_Push | SW_Push | Button_Switch_SMD:SW_SPST_B3U-1000P | Push button switch, generic, two pins
U1, | 1 | MM3Z12VT1 | MM3Z12VT1 | MM3Z12VT1:SOD-323_1P8X1P35_ONS
U2, | 1 | LMR50410YQDBVRQ1 | LMR50410YQDBVRQ1 | LMR5410YQDBVRQ1:DBV0006A-IPC_A
U3, | 1 | LM1117MPX-3.3_NOPB | LM1117MPX-3.3_NOPB | LM1117MPX-3-3-NOPB:DCY0004A_L
U4, | 1 | USBLC6-2SC6 | USBLC6-2SC6 | Package_TO_SOT_SMD:SOT-23-6 | Very low capacitance ESD protection diode, 2 data-line, SOT-23-6
U5, | 1 | ESP32-C3-WROOM-02-N4 | ESP32-C3-WROOM-02-N4 | ESP32-C3-WROOM-02-N4:MODULE_ESP32-C3-WROOM-02-H4
Y1, | 1 | Crystal | Crystal | Crystal:Crystal_SMD_3215-2Pin_3.2x1.5mm | Two pin crystal

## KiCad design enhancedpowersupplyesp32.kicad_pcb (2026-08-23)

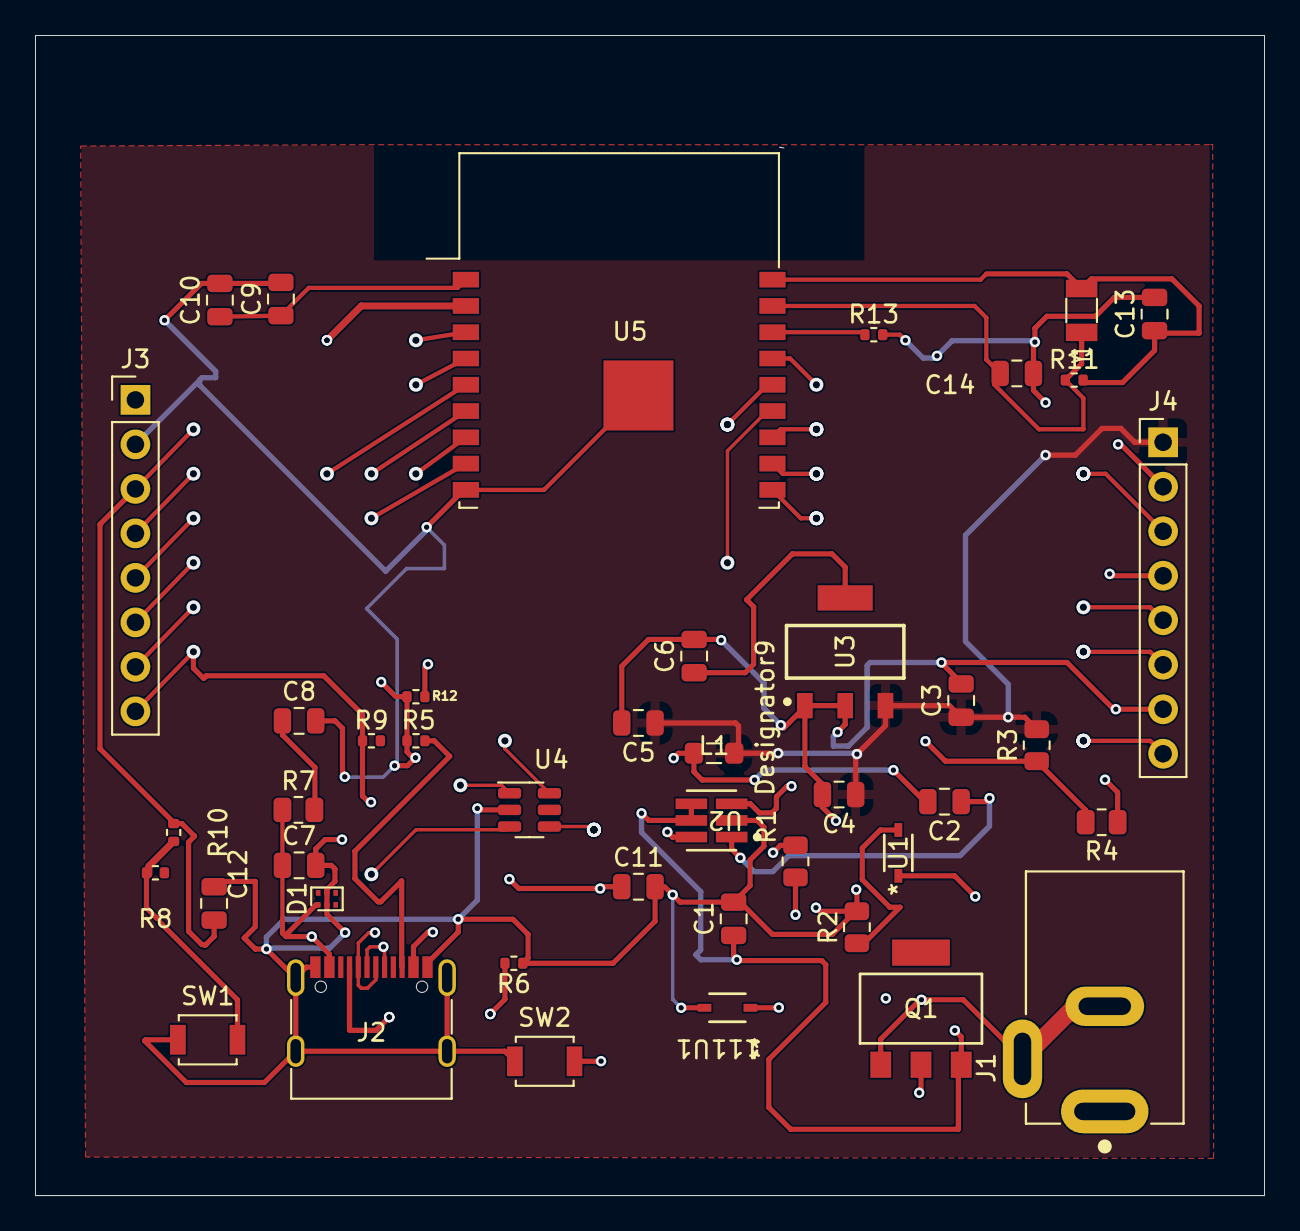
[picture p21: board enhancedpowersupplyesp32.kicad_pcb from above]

Board: 4 copper layers, 70.2 x 66.2 mm, 43 parts (0 on the bottom side), 34 nets.

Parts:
111U1: 3.0SMCJ30A; SOD-323_1P8X1P35_ONS
C1, C5, C6: 10uF; C_0805_2012Metric
C2, C3: 100nF; C_0805_2012Metric
C4: 4.7uF; C_0805_2012Metric
C7, C8, C9, C13, C14: 4u7; C_0805_2012Metric
C10, C11, C12: 100n; C_0805_2012Metric
D1: PESD5V0L4UF; SOT-886
J1: EJ508B; CUI_PJ-202B
J2: USB_C_Receptacle_G-Switch_GT-USB-7010ASV
J3, J4: Conn_01x08_Male; PinHeader_1x08_P2.54mm_Vertical
L1: 4.7uF; L_0805_2012Metric_Pad1.05x1.20mm_HandSolder
Q1: STN3P6F6; SOT223_STN3_STM
R1: F100; R_0805_2012Metric
R2: 100k; R_0805_2012Metric
R3: 88.7k; R_0805_2012Metric
R4: 22.1k; R_0805_2012Metric
R5, R6, R11: 5k1; R_0402_1005Metric
R7: 0R; R_0805_2012Metric
R8, R9, R12, R13: 10k; R_0402_1005Metric
R10: 100k; R_0402_1005Metric
SW1, SW2: SW_Push; SW_SPST_B3U-1000P
U1: MM3Z12VT1; SOD-323_1P8X1P35_ONS
U2: LMR50410YQDBVRQ1; DBV0006A-IPC_A
U3: LM1117MPX-3.3_NOPB; DCY0004A_L
U4: USBLC6-2SC6; SOT-23-6
U5: ESP32-C3-WROOM-02-N4; ESP-WROOM-02
Y1: Crystal; Crystal_SMD_3215-2Pin_3.2x1.5mm

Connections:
+5V: C3.1 (A), C4.1 (A), C5.1 (A), J4.1, L1.1 (A), R3.2, U3.3 (INPUT)
/D+: J2.A6 (D+), J2.B6 (D+), U4.1 (I/O1)
/D-: J2.A7 (D-), J2.B7 (D-), U4.6 (I/O1)
/Vin: J1.1, R1.1
/Vin_F: C1.1, Q1.3 (S), U1.1 (K), U2.4 (EN), U2.5 (VIN)
EN: C12.1, J3.3, R10.1, U5.2 (EN)
GND: 111U1.2 (A), C1.2, C3.2 (B), C4.2 (B), C5.2 (B), C6.2 (B), C7.2, C8.2, C9.2, C10.2, C11.2, C12.2, C13.2, C14.2, D1.2 (A), D1.5 (A), J1.2, J1.3, J2.A1 (GND), J2.A12 (GND), J2.B1 (GND), J2.B12 (GND), J2.S1 (SHIELD), J3.2, J4.2, J4.4, J4.7, Q1.1 (G), R2.2, R4.1, R5.1, R6.1, R12.2, R13.2, SW1.1, SW2.1, U2.2 (GND), U3.1 (GND), U3.2 (OUT), U4.2 (GND), U5.9 (GND), U5.19 (GND)
I02: R13.1, U5.16 (IO2)
I03: J4.3, U5.15 (IO3)
I04: J3.4, U5.3 (IO4)
I05: J3.5, U5.4 (IO5)
I06: J3.6, U5.5 (IO6)
I07: J3.7, U5.6 (IO7)
I08: R12.1, U5.7 (IO8)
I09: C11.1, J3.8, R9.1, SW2.2, U5.8 (IO9)
I010: J4.8, U5.10 (IO10)
unnamed: 111U1.1 (K), Q1.2 (D), R1.2
unnamed: C2.1 (A), U2.1 (CB)
unnamed: C2.2 (B), L1.2 (B), U2.6 (SW)
unnamed: C6.1 (A), U3.4 (OUT)
unnamed: C8.1, R7.2
unnamed: C9.1, C10.1, U5.1 (3V3)
unnamed: C13.1, R11.2, U5.18 (IO0), Y1.1
unnamed: C14.1, R11.1, U5.17 (IO1), Y1.2
unnamed: J2.A5 (CC1), R6.2
unnamed: J2.B5 (CC2), R5.2
unnamed: R2.1, U1.2 (A)
unnamed: R3.1, R4.2, U2.3 (FB)
unnamed: R8.1, R10.2, SW1.2
RX: J4.6, U5.11 (RXD)
TX: J4.5, U5.12 (TXD)
USB_D+: U4.3 (I/O2), U5.14 (IO19)
USB_D-: U4.4 (I/O2), U5.13 (IO18)
VBUS: C7.1, D1.1 (K1), J2.A4 (VBUS), J2.A9 (VBUS), J2.B4 (VBUS), J2.B9 (VBUS), R7.1

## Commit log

2026-08-23 Add Enhanced Power Supply ESP32 PCB design
    [enhancedpowersupplyesp32.csv, enhancedpowersupplyesp32.kicad_pcb, enhancedpowersupplyesp32.kicad_sch]
2026-08-23 Add PCB report and ERC documentation

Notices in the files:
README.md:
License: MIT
